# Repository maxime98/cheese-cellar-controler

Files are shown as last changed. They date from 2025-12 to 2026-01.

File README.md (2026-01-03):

🧀 Cheese Controller — ESP32-S2
Temperature & Humidity Controller for Cheese Aging
This project implements an ESPHome-based controller running on an ESP32-S2, designed for cheese aging (raclette, reblochon, tomme, etc.) inside a modified freezer or refrigerator.
The main goal is slow, controlled thermal stability, respecting the high thermal inertia of cheese — without aggressive PID control.

🎯 System Goals
Maintain a stable core (probe) temperature
Avoid overshoot (too cold)
Protect the cheese rind from thermal shock
Regulate humidity
Provide full observability (LCD + Home Assistant)

🧠 Control Philosophy

❌ No PID
✅ Zone-based logic with adaptive timing

Why?

Very high thermal inertia (cheese + air + enclosure)
Long response delays
PID tends to oscillate and overcorrect in this context

🌡️ Temperature Control — Overview
Sensors
Probe (DS18B20 / Dallas)
→ primary control sensor (cheese mass)
Air (DHT22)
→ safety + thermal buffer (not the main control)

Temperature Zones Around Setpoint (SP)
Zone	ΔT = Probe − SP	Behavior
FAR	> Temp FAR delta	Longer cooling cycles
MID	between MID delta and FAR delta	Interpolated behavior
NEAR	< MID delta	Short cycles + long pauses
⏱️ Intelligent Timing (Core of the System)
1️⃣ Dynamic Minimum OFF Time
The closer the probe is to the setpoint, the longer the controller waits before restarting cooling.
R1 NEAR Min OFF
R1 OFF Bonus near (progressive bonus close to SP)
👉 Prevents compressor short-cycling and temperature pumping.

2️⃣ Temperature Slope (dT/dt) Brake
The controller computes the temperature slope in °C per 10 minutes:
d > 0 → probe still cooling → wait longer
d ≈ 0 → stable
d < 0 → probe warming → react sooner
This prevents the classic failure mode:
“Waited too long → temperature starts rising again”

❄️ Air Temperature Safety (Anti-Shock)
Air temperature does not control the system, but protects it.
Latch ON threshold:
air < SP - air_safety_delta
Latch OFF threshold (hysteresis):
air > (SP - air_safety_delta + air_safety_hyst)

Behavior:
Latch ON → compressor blocked
Latch OFF → normal control
👉 Prevents excessively cold air, condensation, and rind damage.

💧 Humidity Control
Simple ON / OFF logic
max_on + min_off
Intentionally gentle and conservative

📟 LCD Display (20×4)

Displays in real time:
Air temperature & humidity
Probe temperature & setpoint
Relay states (R1 / R2)
Remaining wait time
Temperature slope (d = °C/10m)
Clock

🧪 Debug & Observability (Home Assistant)
🔍 Cheese Debug Line (Copy / Paste Friendly)

A text_sensor exposes all key values in a single line:

Air=10.6C 100% | Prb=12.27C | SP=12.00 band=0.50 |
d=0.00C/10m | zone=NEAR |
R1=0 latch=0 (cut=4.5/5.1) |
hot=0 cold=0 | R2=0

➡️ Easy to copy from Developer Tools → States
➡️ Ideal for remote troubleshooting and tuning

🚨 Built-in Safeties
Compressor anti-short-cycle
Immediate shutdown if:
air too cold
probe too cold
Boot inhibition (10 seconds)
Fault detection:
relay ON but no current detected
Safe behavior if sensors return NaN

⚙️ Recommended Settings (12 °C Aging)
Parameter	Value
Temp Band	0.4 – 0.6 °C
Temp MID delta	0.8 – 1.0 °C
Temp FAR delta	2.5 – 3.0 °C
R1 FAR Max ON	~360 s
R1 NEAR Max ON	~90 s
R1 NEAR Min OFF	600 s
R1 OFF Bonus near	300–600 s
Probe Fast Drop	1.0 °C / 10 min
Air safety delta	7–8 °C
Air safety hysteresis	0.4–0.8 °C
🧀 Expected Behavior

Slow, controlled temperature convergence
No overshoot
Minimal compressor cycling
Healthy, stable rind development
Predictable, explainable control behavior

📌 Final Notes
This controller is designed for:
Artisan cheese aging
Experimental but controlled environments

Understanding and tuning over blind automation

It prioritizes readability, predictability, and robustness over complexity

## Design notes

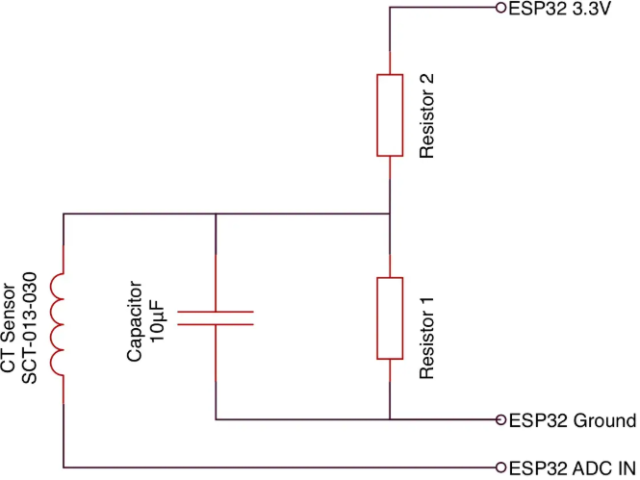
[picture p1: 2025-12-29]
Capture d’écran 2025-12-29 183743.png

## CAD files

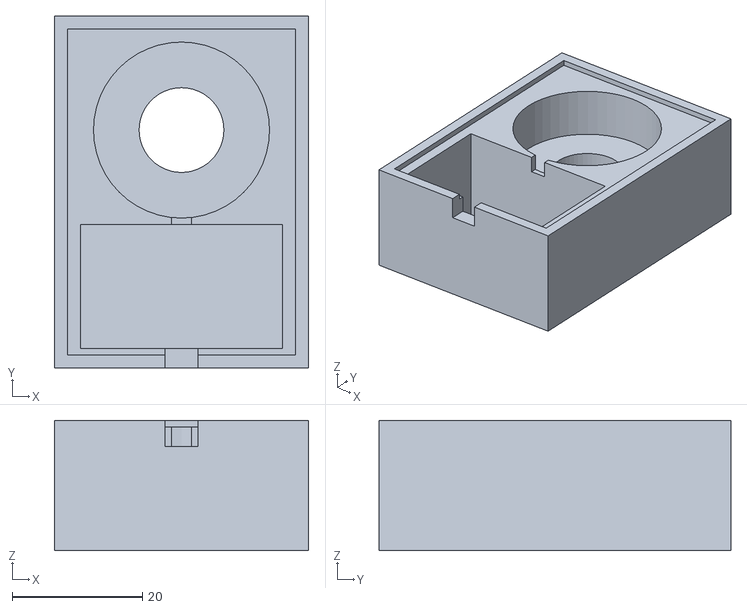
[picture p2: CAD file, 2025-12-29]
petite boite pour humidificateur.stl
39.0 x 54.0 x 20.0

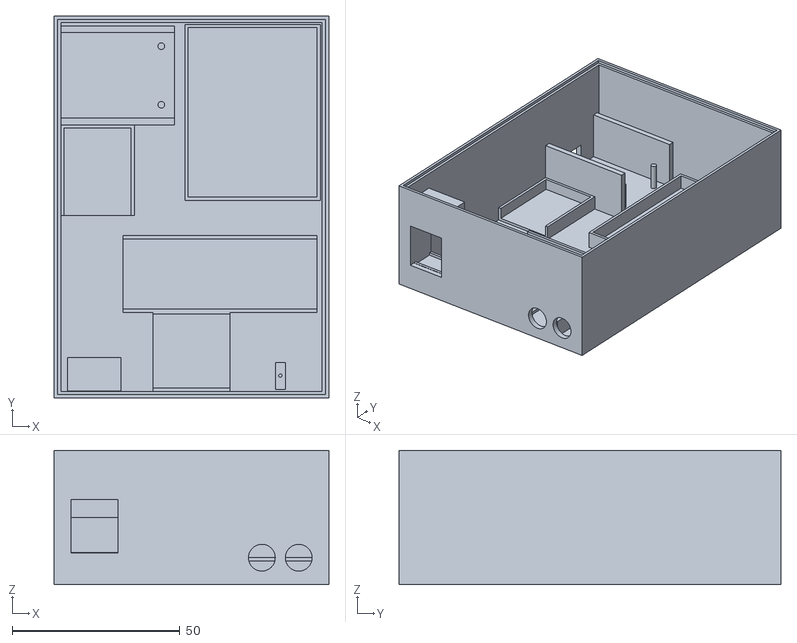
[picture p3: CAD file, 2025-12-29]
boite.stl
82.0 x 114.0 x 40.0

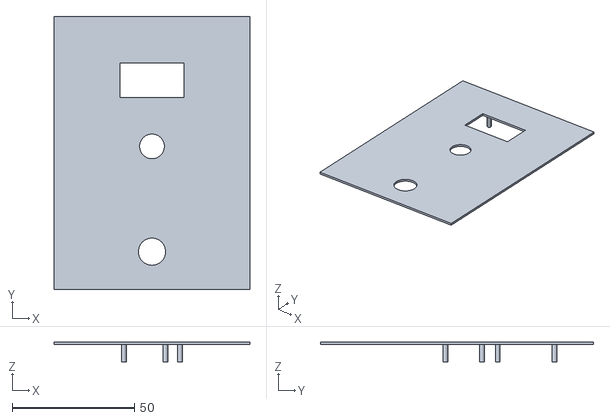
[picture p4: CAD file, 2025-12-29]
plaque dessus box.stl
80.0 x 111.5 x 8.00

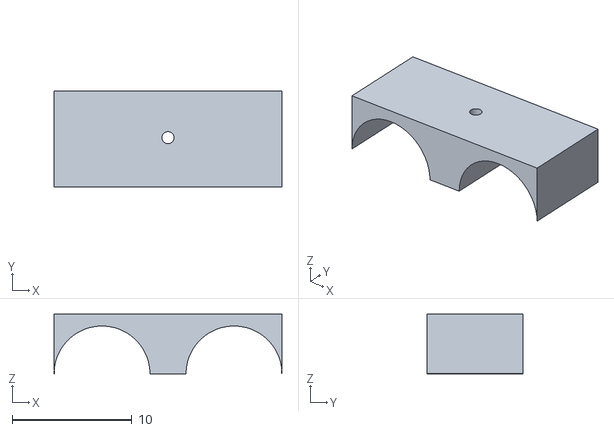
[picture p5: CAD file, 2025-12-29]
serre cable.stl
19.0 x 8.00 x 5.00

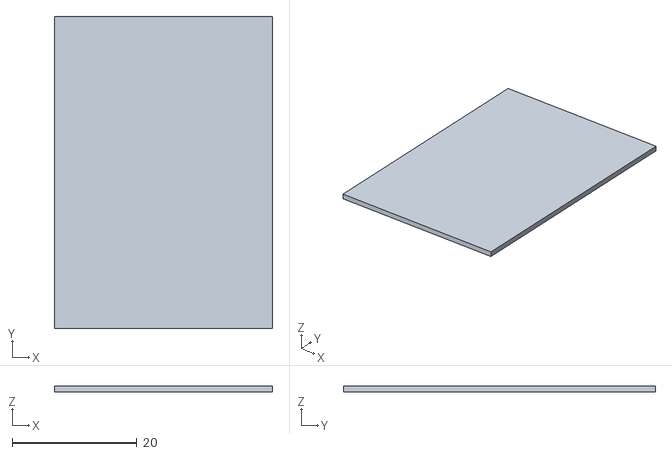
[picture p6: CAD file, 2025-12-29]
couvercle petite boite pour humidificateur.stl
35.0 x 50.0 x 1.00

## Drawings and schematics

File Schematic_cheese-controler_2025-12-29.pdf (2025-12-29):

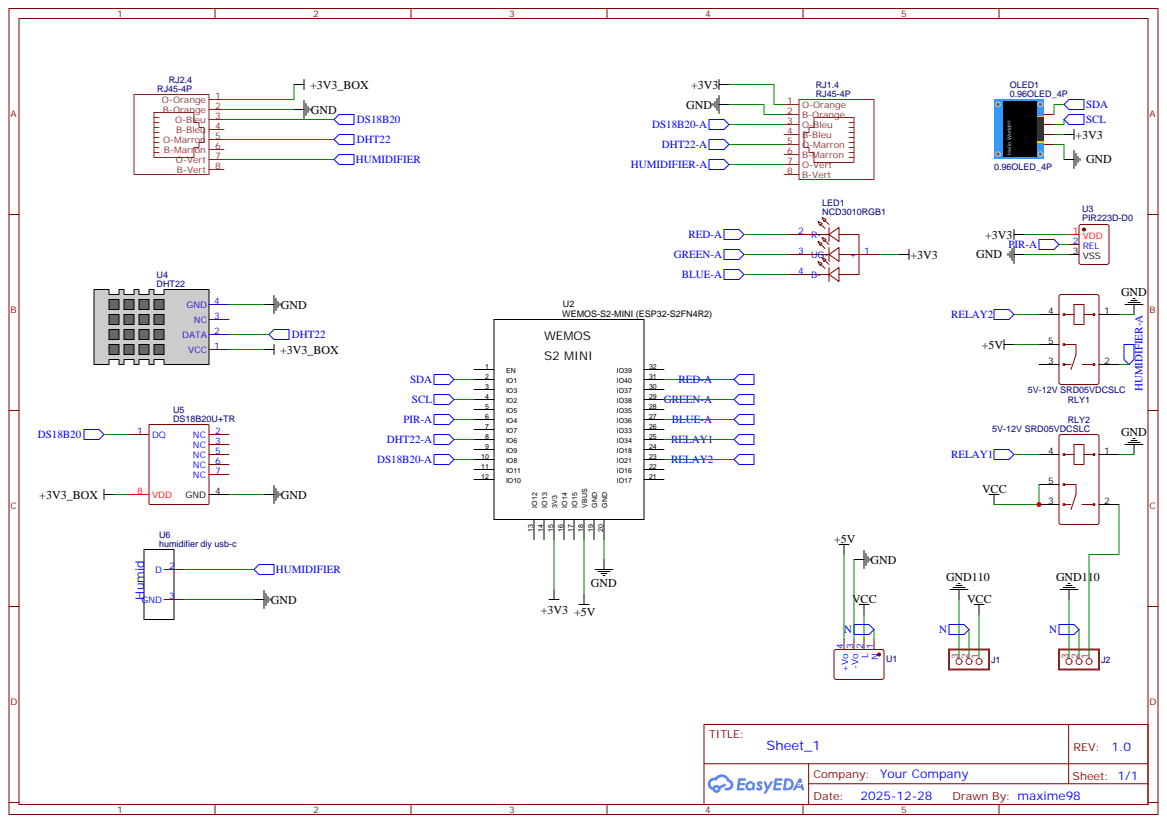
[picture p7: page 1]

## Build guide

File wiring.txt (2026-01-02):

schéma ASCII de câblage clair (avec notes) pour ton montage ESP32-S2 mini + LCD2004 I2C + DHT22 + DS18B20 + PIR + CT clamp + 2 relais.

⚠️ Sécurité : tout ce qui est AC/mains (120V/230V) doit être fait dans un boîtier, avec serre-câbles, fusible si possible, et isolation. Ne branche jamais le secteur directement sur l’ESP32.

1) Vue d’ensemble (basse tension)
                 +----------------------+
                 |   ESP32-S2 mini      |
                 | (LOLIN S2 mini)      |
                 |                      |
I2C SCL  GPIO1 ---+-------------------+ |      +------------------+
I2C SDA  GPIO2 ---+-------------------|-+------| LCD2004 + PCF8574|
GND      GND  ----+-------------------|-+------| GND              |
5V       5V   ----+-------------------|-+------| VCC (5V)         |
                 |                   | |      | SDA / SCL (I2C)   |
DS18B20  GPIO8 ---+---- DATA         | |      +------------------+
                 |                   | |
DHT22    GPIO6 ---+---- DATA         | |
PIR      GPIO4 ---+---- OUT          | |
ADC CT   GPIO10 --+---- ADC IN       | |
Relay1   GPIO34 --+---- IN1          | |
Relay2   GPIO21 --+---- IN2          | |
                 +----------------------+

Power:
- ESP32 powered by 5V (USB or 5V PSU)
- LCD2004 (PCF8574) powered by 5V
- Relay board powered by 5V (recommended separate 5V PSU if relays are noisy)
- All GND must be common (ESP32, relay board, sensors, LCD)

2) LCD 20x4 I2C (PCF8574)
LCD2004 PCF8574 board     ESP32-S2 mini
---------------------     ------------
VCC (5V)  -------------   5V
GND       -------------   GND
SDA       -------------   GPIO2 (SDA)
SCL       -------------   GPIO1 (SCL)

Address typically: 0x27 (sometimes 0x3F)
Backlight: controlled via it.backlight() / it.no_backlight()
(PCF8574 jumper must be closed for backlight control)

3) PIR motion sensor (pour backlight)
PIR Sensor              ESP32-S2 mini
---------              ------------
VCC  -------------     3.3V (or 5V if sensor supports it)
GND  -------------     GND
OUT  -------------     GPIO4  (INPUT_PULLDOWN in config)

Si ton PIR sort du 5V en OUT : mets un diviseur ou vérifie qu’il est compatible 3.3V.

4) DS18B20 (cheese probe temp) sur OneWire
Recommandé (3 fils + résistance pull-up 4.7k)
DS18B20                  ESP32-S2 mini
-------                  ------------
VDD  -------------       3.3V
GND  -------------       GND
DQ   -------------       GPIO8

Pull-up:
3.3V ---[4.7k]--- DQ (GPIO8)

5) DHT22 (air temp/humidity)
DHT22                    ESP32-S2 mini
-----                    ------------
VCC  -------------       3.3V (or 5V depending module)
GND  -------------       GND
DATA -------------       GPIO6

Pull-up:
3.3V ---[10k]--- DATA (if not already on the module)

6) Relais 2 canaux (Freezer + Humidifier)
Relay Board (2ch)        ESP32-S2 mini
------------------       ------------
VCC (5V)  -----------    5V
GND       -----------    GND
IN1       -----------    GPIO34   (Relay 1 Freezer)
IN2       -----------    GPIO21   (Relay 2 Humidifier)

Si c’est un relais “low level trigger” et que tu as inverted: true, c’est normal : ON = niveau bas.

7) Câblage AC (Mains) — RELAY 1 Freezer, RELAY 2 Humidifier
Principe standard (couper la phase / hot)
Mains HOT (L)  ----->  COM (Relay)
                      NO  (Relay) -----> HOT vers appareil
Mains NEUTRAL (N) ----------------------> NEUTRAL vers appareil
EARTH (PE) -----------------------------> Terre vers appareil (si présent)

Freezer (Relay 1)
HOT (L) -> Relay1 COM
Relay1 NO -> Hot Freezer
Neutral -> Neutral Freezer
Ground -> Ground Freezer

Ultrasonic humidifier (Relay 2)
HOT (L) -> Relay2 COM
Relay2 NO -> Hot Humidifier
Neutral -> Neutral Humidifier

Utilise NO (Normally Open) pour que tout soit OFF par défaut.

8) CT Clamp (SCT-030) + module conditionneur -> ADC GPIO10

⚠️ Important : une CT clamp ne se branche pas directement sur l’ADC sans conditionnement (burden + offset + filtrage).
Tu sembles avoir un circuit donnant un signal centré vers ~1.65V (midpoint).

Schéma conceptuel
Freezer HOT wire
     |
     |  (CT Clamp around ONE wire ONLY)
    ( )
     |
CT Clamp output --> burden resistor + rect/filter (or conditioning board)
                 --> biased to mid-voltage (~1.65V)
                 --> ADC OUT -----> GPIO10 (ADC)
GND --------------------------------> GND ESP32

Si tu utilises un module type “current sensor board” :

CT Board OUT  -----> GPIO10
CT Board GND  -----> GND
CT Board VCC  -----> 3.3V or 5V (as required)
